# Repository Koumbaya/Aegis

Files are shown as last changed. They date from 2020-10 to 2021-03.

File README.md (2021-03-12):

# Aegis
  
 The Aegis is a keyboard that uses the same layout as the crkbd by foostan : https://github.com/foostan/crkbd
 
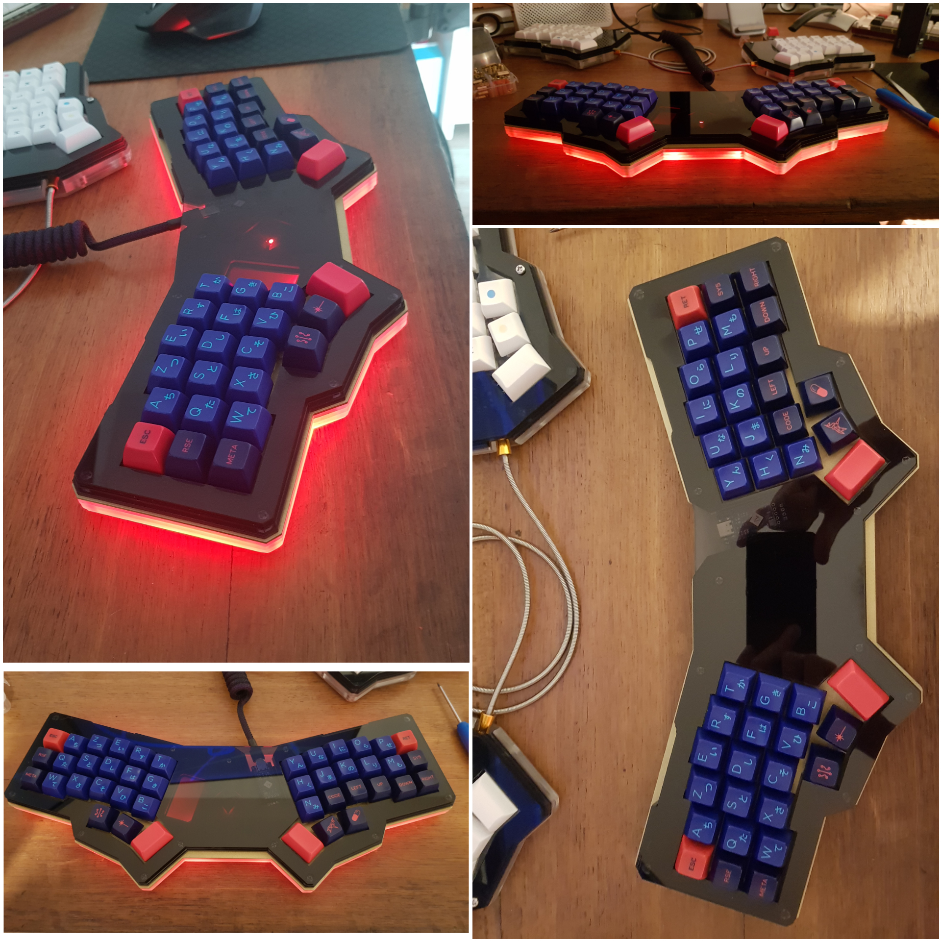
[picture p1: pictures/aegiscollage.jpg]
 
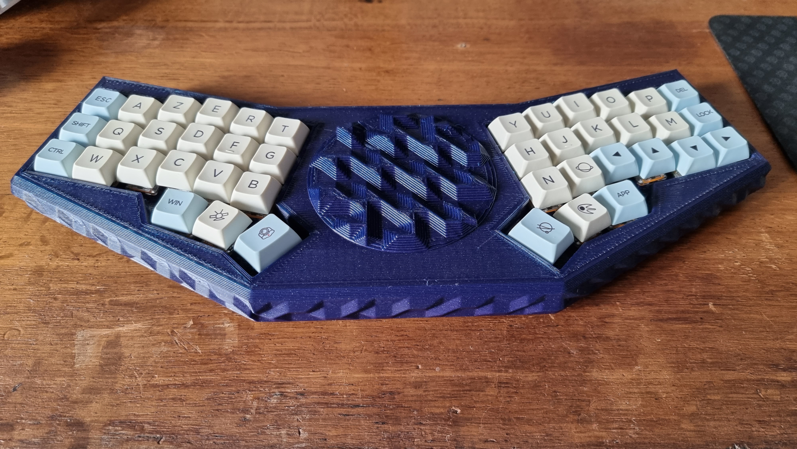
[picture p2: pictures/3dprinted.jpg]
 
 
 I wanted certain features like the solenoid so I made a quick PCB that's similar in layout to a crkbd but with only one pro-micro, you can make this PCB if you want a single PCB with underglow and a solenoid, or you can take the crkbd version of the case and slap both halves into this bad boy !
With the brass plate, it weight around 1Kg.
 
### CASE

If you're going for a metal 1,5mm switchplate (which you should, better sound yay !), you'll need to cut :
- One of every : Aegis_top1, Aegis_top2, Aegis_top3, Aegis_bottom in 3mm acrylic.
- Three times the Aegis_middle in 3mm acrylic
- One Aegis_switch_plate in 1,5mm metal of your choosing.

If you want to make everything in acrylic : just do as above minus one Aegis_middle.

You'll need 13 x M3 hex standoffs, >9mm if you have 3 "middle" part, >6 if you have only 2.
I've noticed that nylon standoffs are way larger than brass standoffs, so the dxf are designed for nylon standoff (brass ones will turn free) but can be modified.
You'll also need 13 x M3x5mm and 13 x M3x8mm screws.
The screws heads are hidden underneath the topmost plate, so you'll need something to hold it in place, probably some slim double-sided tape (will update once I've tested).
Note : be careful with the top1 and top2 cutouts, I broke mine when peeling the protective plastic sheet. (shoudn't have this problem on the crkbd version I think

### 3D printed case

This one is pretty much straightforward : print, put PCB inside, close.
There is a CRKBD version too.

 ### PCB
 
 The footprints for the diodes are either THT or SMD.
 
 The PCB uses SK6812mini-E for easier soldering, but the footprints are inverted compared to most keyboards :
 here the underglow LEDs are soldered from under the PCB (facing you when you solder them), instead of being soldered from the top. 
 
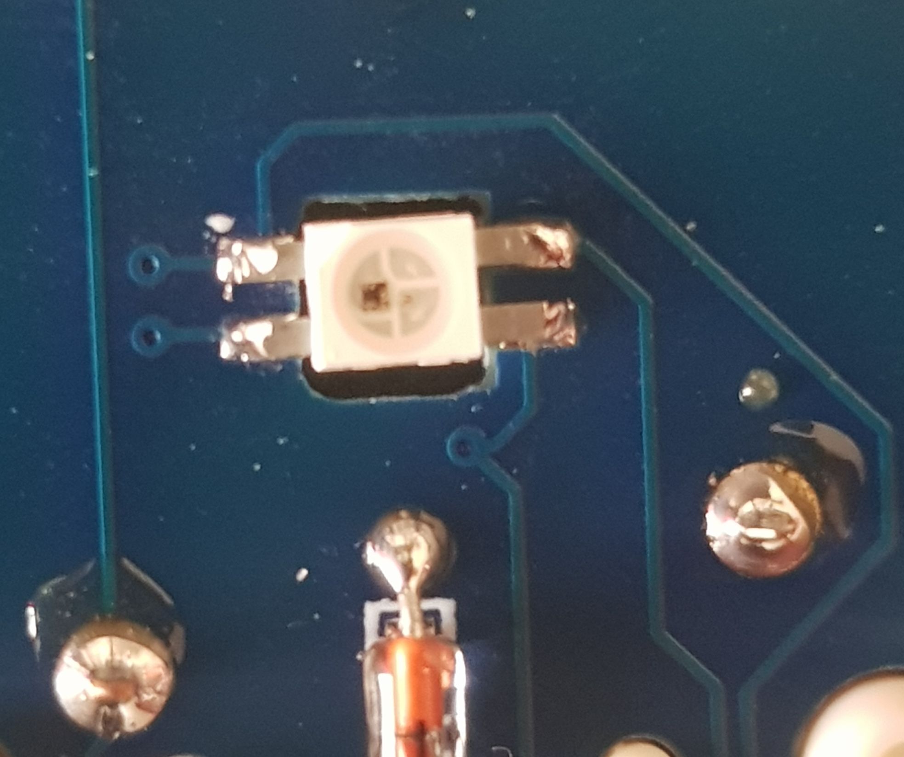
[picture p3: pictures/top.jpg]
top


(soldered from under the PCB, led facing you. beware of the different orientations : the cut tab goes with the dot on the PCB)
 
 I did this because on my previous board some of the LEDs failed after that I had soldered all of the switches, meaning that to change them I had to desolder the switches.
 
 The center LED is soldered like a switch backlight led (from under the PCB, shining towards the top, through the PCB) because it's here to shine on the plate which have a logo cutout (a version without the logo is also available, in which case you'll probably want to just jump the trace for the led from IN to OUT).
 
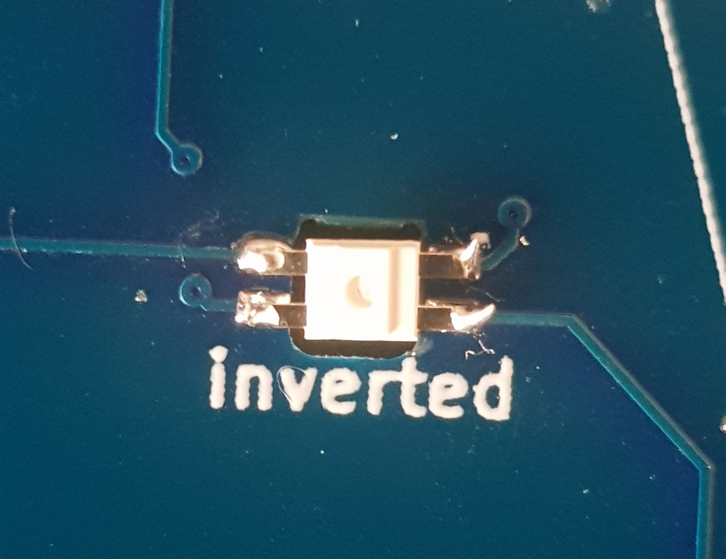
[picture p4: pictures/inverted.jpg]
inverted


(the cut tab goes on the top/right orientation, led facing back at you)

 For the solenoid you'll need 1 TIP120, 1 1N4001 diode, 1 1.1KOhms resistor and 1 5V solenoid.
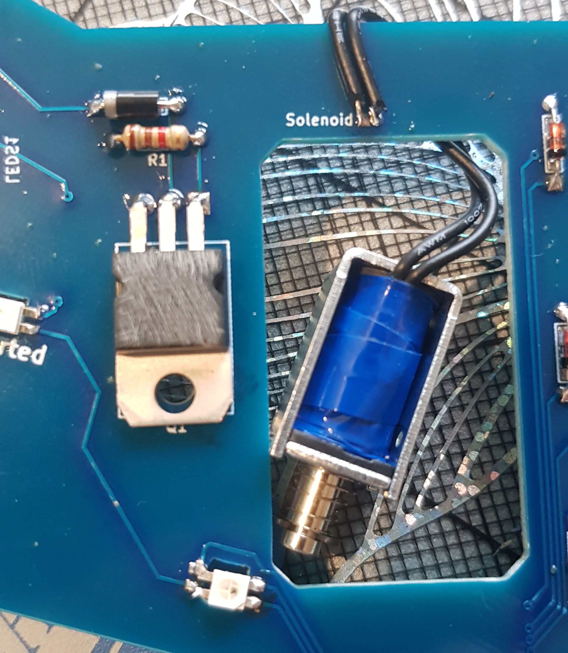
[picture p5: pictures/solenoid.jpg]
solenoid
Should look like this 
Note : in the v1.1, I've added a hole for the TIP120 because it's too big (by 0.3mm) to fit in the case. In mine I had to sand it down.

Note 2 : I couldn't get the solenoid to work :( with a pro micro I got a reboot, with the elite-c I discovered that the RAW port doesn't exist on it, so I took the VCC, with the same result. I've checked the schematics with some people and it should be good, so I'm putting in on the PCB anyway if someone want to have a crack at it(I've added 2 jumpers to get either VCC or RAW to the solenoid, if you have a pro micro, solder RAW, elite-c : solder VCC. Never both). If you find a solution let me know.

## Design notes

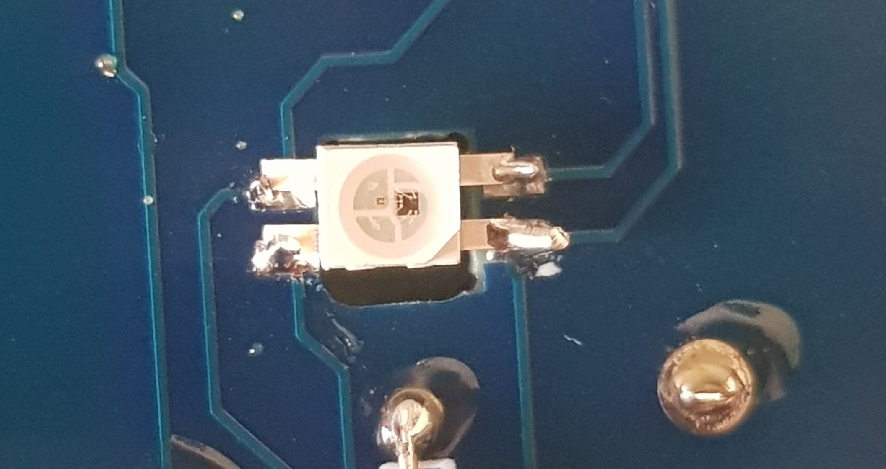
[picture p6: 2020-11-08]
pictures/bottom.jpg

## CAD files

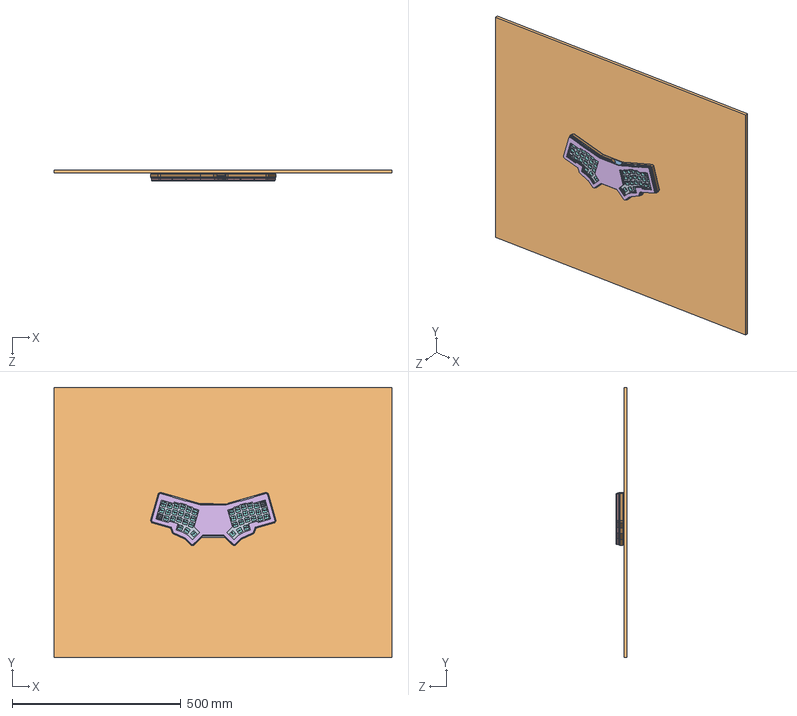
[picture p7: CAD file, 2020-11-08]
case_aegis_version/Aegis_Assemblage1.SLDASM
1000.0 x 800.0 x 33.5 mm
Aegis_switch_plate
Aegis_middle x 3
Aegis_bottom
Aegis_top1
Aegis_top2
Aegis_top3
Pièce1
pcb_export
cherry mx x 2

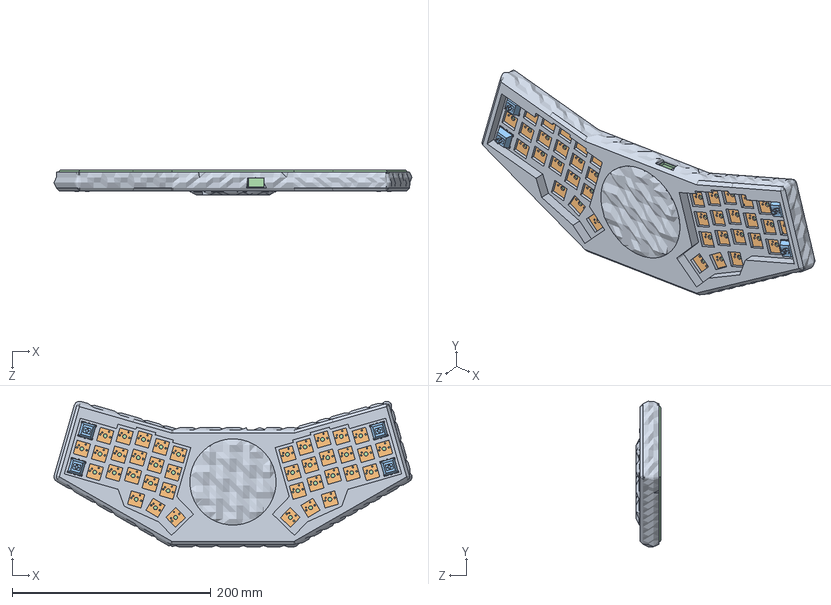
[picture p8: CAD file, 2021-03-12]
case_3D/Assemblage1.SLDASM
360.1 x 146.4 x 24.9 mm
Aegis_switch_plate_nologo
pcb_export
cherry mx x 4
bottom

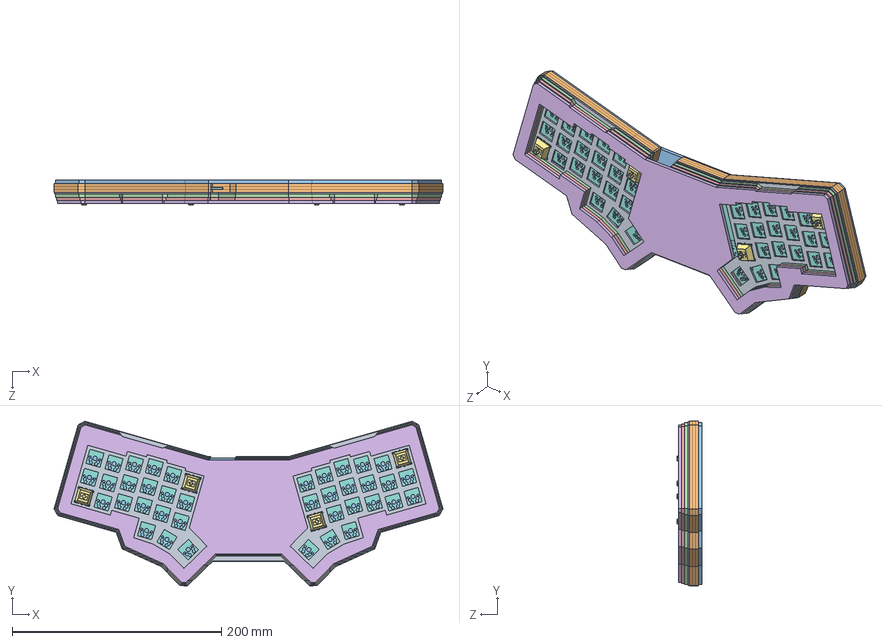
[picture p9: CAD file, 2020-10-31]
case_crkbd_version/Aegis_Assemblage1.SLDASM
371.9 x 157.4 x 23.7 mm
Aegis_switch_plate
Aegis_middle x 3
Aegis_bottom
Aegis_top1
Aegis_top2
Aegis_top3
cherry mx x 4
PCB x 2

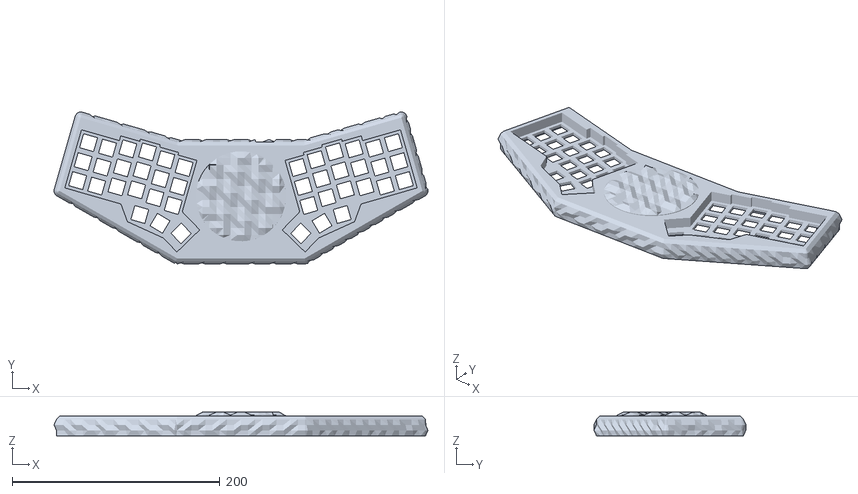
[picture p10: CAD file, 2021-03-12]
case_3D/Aegis_switch_plate_nologo.STL
360.1 x 146.4 x 22.9

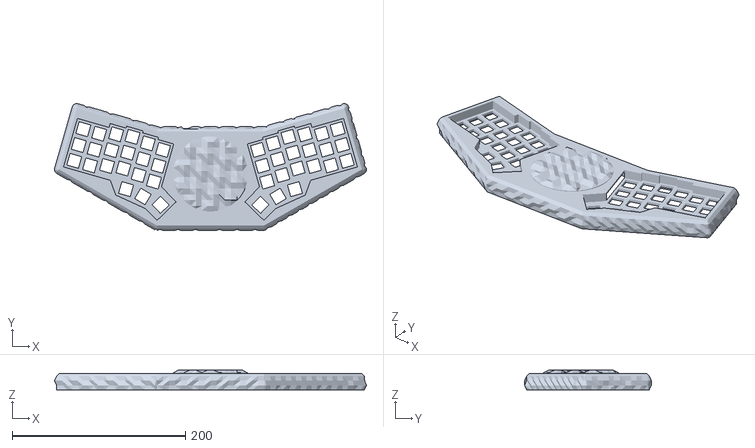
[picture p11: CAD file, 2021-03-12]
case_3D/crkbd version/Aegis_switch_plate_nologo.STL
360.1 x 146.4 x 22.9

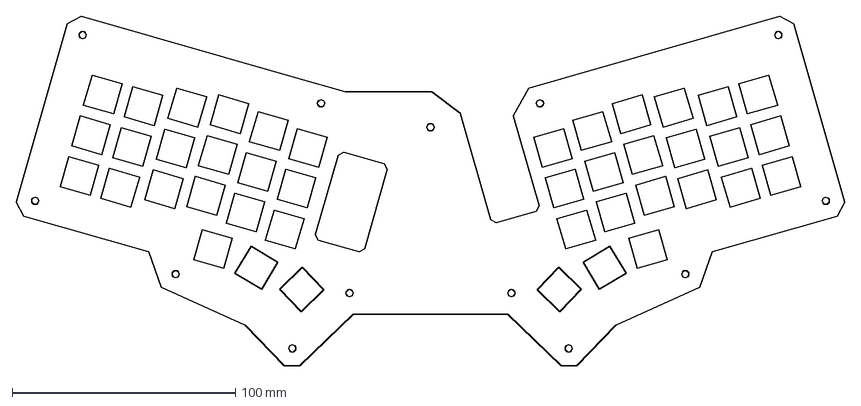
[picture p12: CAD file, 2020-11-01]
case_aegis_version/cutouts/Aegis_switch_plate_nologo.DXF
371.2 x 156.7 mm

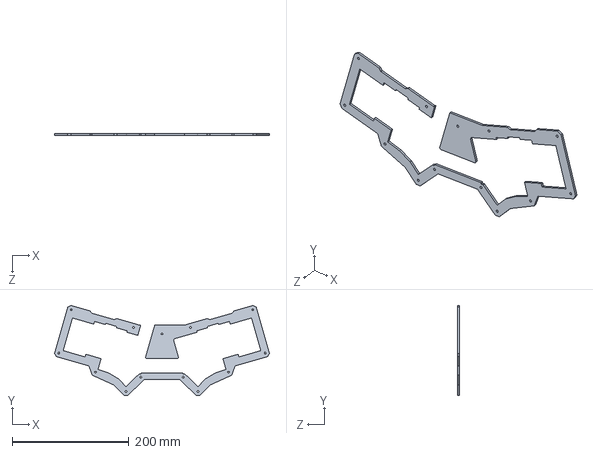
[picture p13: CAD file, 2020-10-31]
case_crkbd_version/Aegis_top1.SLDPRT
369.1 x 154.7 x 3.00 mm

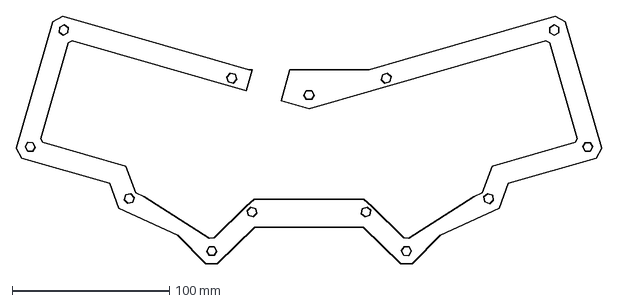
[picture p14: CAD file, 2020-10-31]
case_crkbd_version/cutouts/Aegis_middle.DXF
371.9 x 157.4 mm

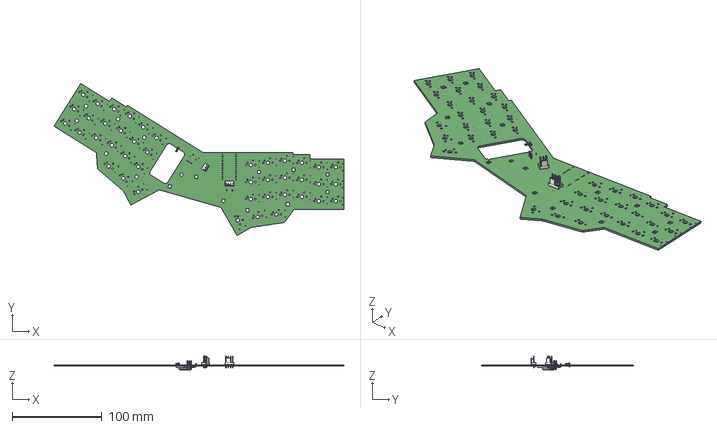
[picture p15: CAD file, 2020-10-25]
PCB/aegis/aegis.step
323.8 x 169.8 x 16.1 mm

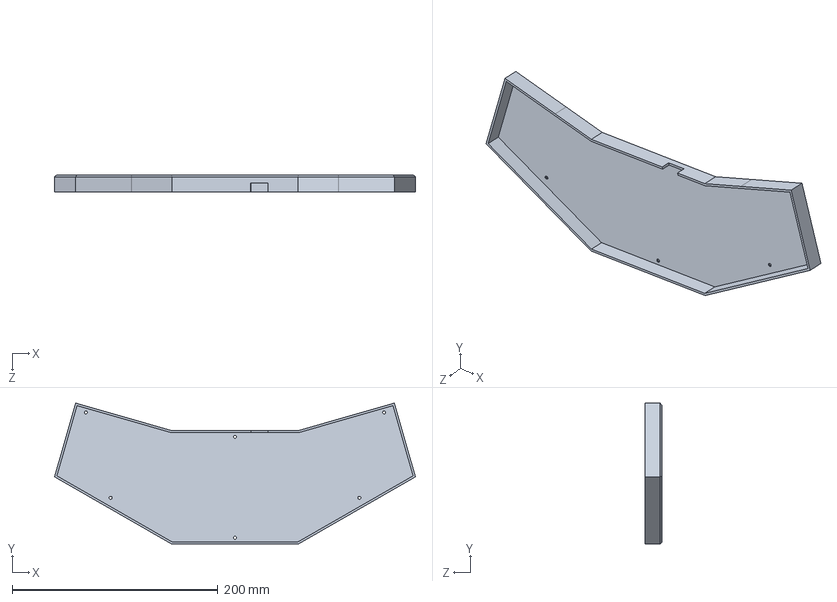
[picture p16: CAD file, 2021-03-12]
case_3D/bottom.SLDPRT
350.8 x 136.9 x 17.0 mm

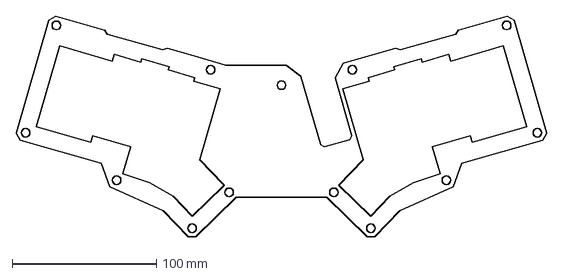
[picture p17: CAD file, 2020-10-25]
case_aegis_version/cutouts/Aegis_top2.DXF
366.9 x 152.6 mm

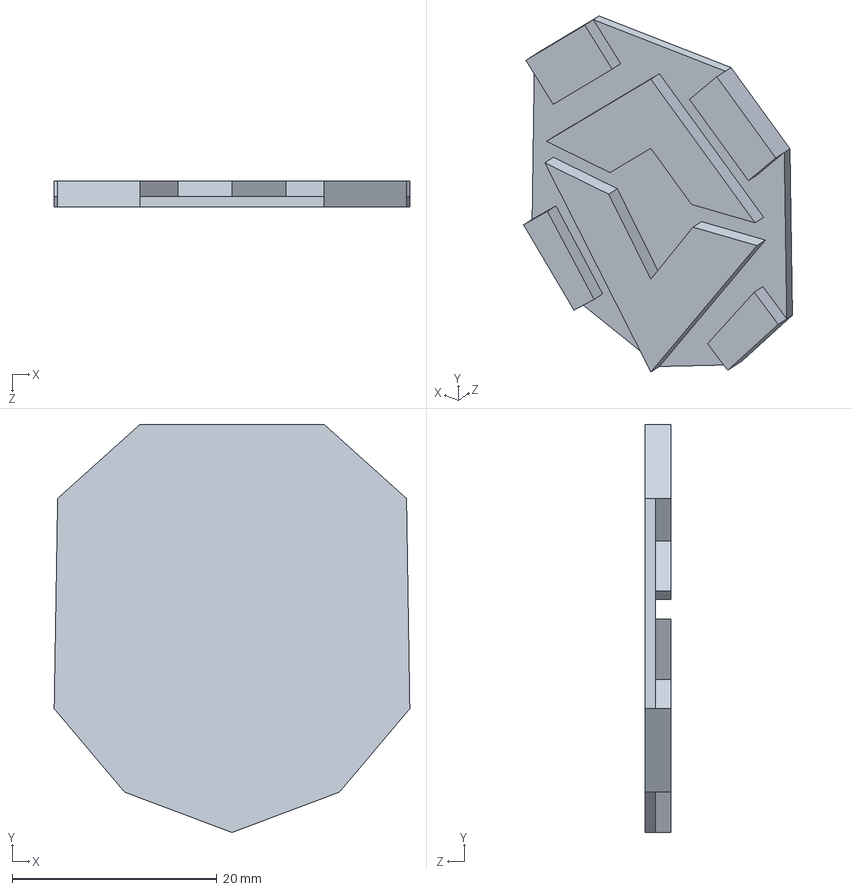
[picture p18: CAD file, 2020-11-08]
case_aegis_version/logo.SLDPRT
34.7 x 39.9 x 2.50 mm

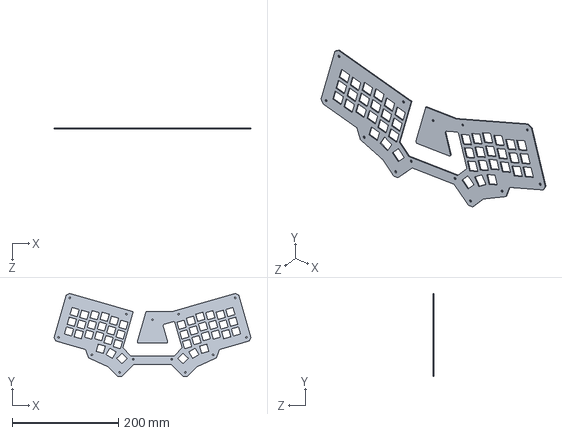
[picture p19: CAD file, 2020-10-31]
case_crkbd_version/Aegis_switch_plate.SLDPRT
371.2 x 156.7 x 1.50 mm

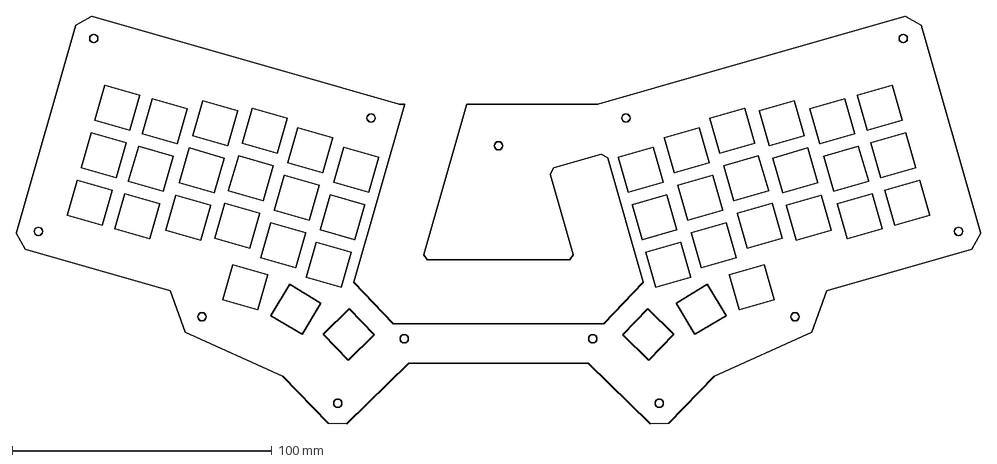
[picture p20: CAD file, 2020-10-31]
case_crkbd_version/cutouts/Aegis_switch_plate.DXF
371.2 x 156.7 mm

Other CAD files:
case_3D/crkbd version/bottom.SLDPRT
case_aegis_version/Aegis_bottom.SLDPRT
case_aegis_version/cutouts/Aegis_bottom.DXF
case_3D/bottom.STL
case_3D/crkbd version/bottom.STL
case_aegis_version/Aegis_middle.SLDPRT
case_aegis_version/Aegis_switch_plate.SLDPRT
case_aegis_version/Aegis_switch_plate_nologo.SLDPRT
case_aegis_version/Aegis_top1.SLDPRT
case_aegis_version/Aegis_top2.SLDPRT
case_aegis_version/Aegis_top3.SLDPRT
case_aegis_version/Pièce1.SLDPRT
case_aegis_version/cutouts/Aegis_middle.DXF
case_aegis_version/cutouts/Aegis_switch_plate.DXF
case_aegis_version/cutouts/Aegis_top1.DXF
case_aegis_version/cutouts/pcb_model.DXF
case_aegis_version/logo.STL
case_aegis_version/pcb_export.SLDPRT
case_aegis_version/pcb_model.SLDPRT
case_crkbd_version/Aegis_bottom.SLDPRT
case_crkbd_version/Aegis_middle.SLDPRT
case_crkbd_version/Aegis_top2.SLDPRT
case_crkbd_version/Aegis_top3.SLDPRT
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

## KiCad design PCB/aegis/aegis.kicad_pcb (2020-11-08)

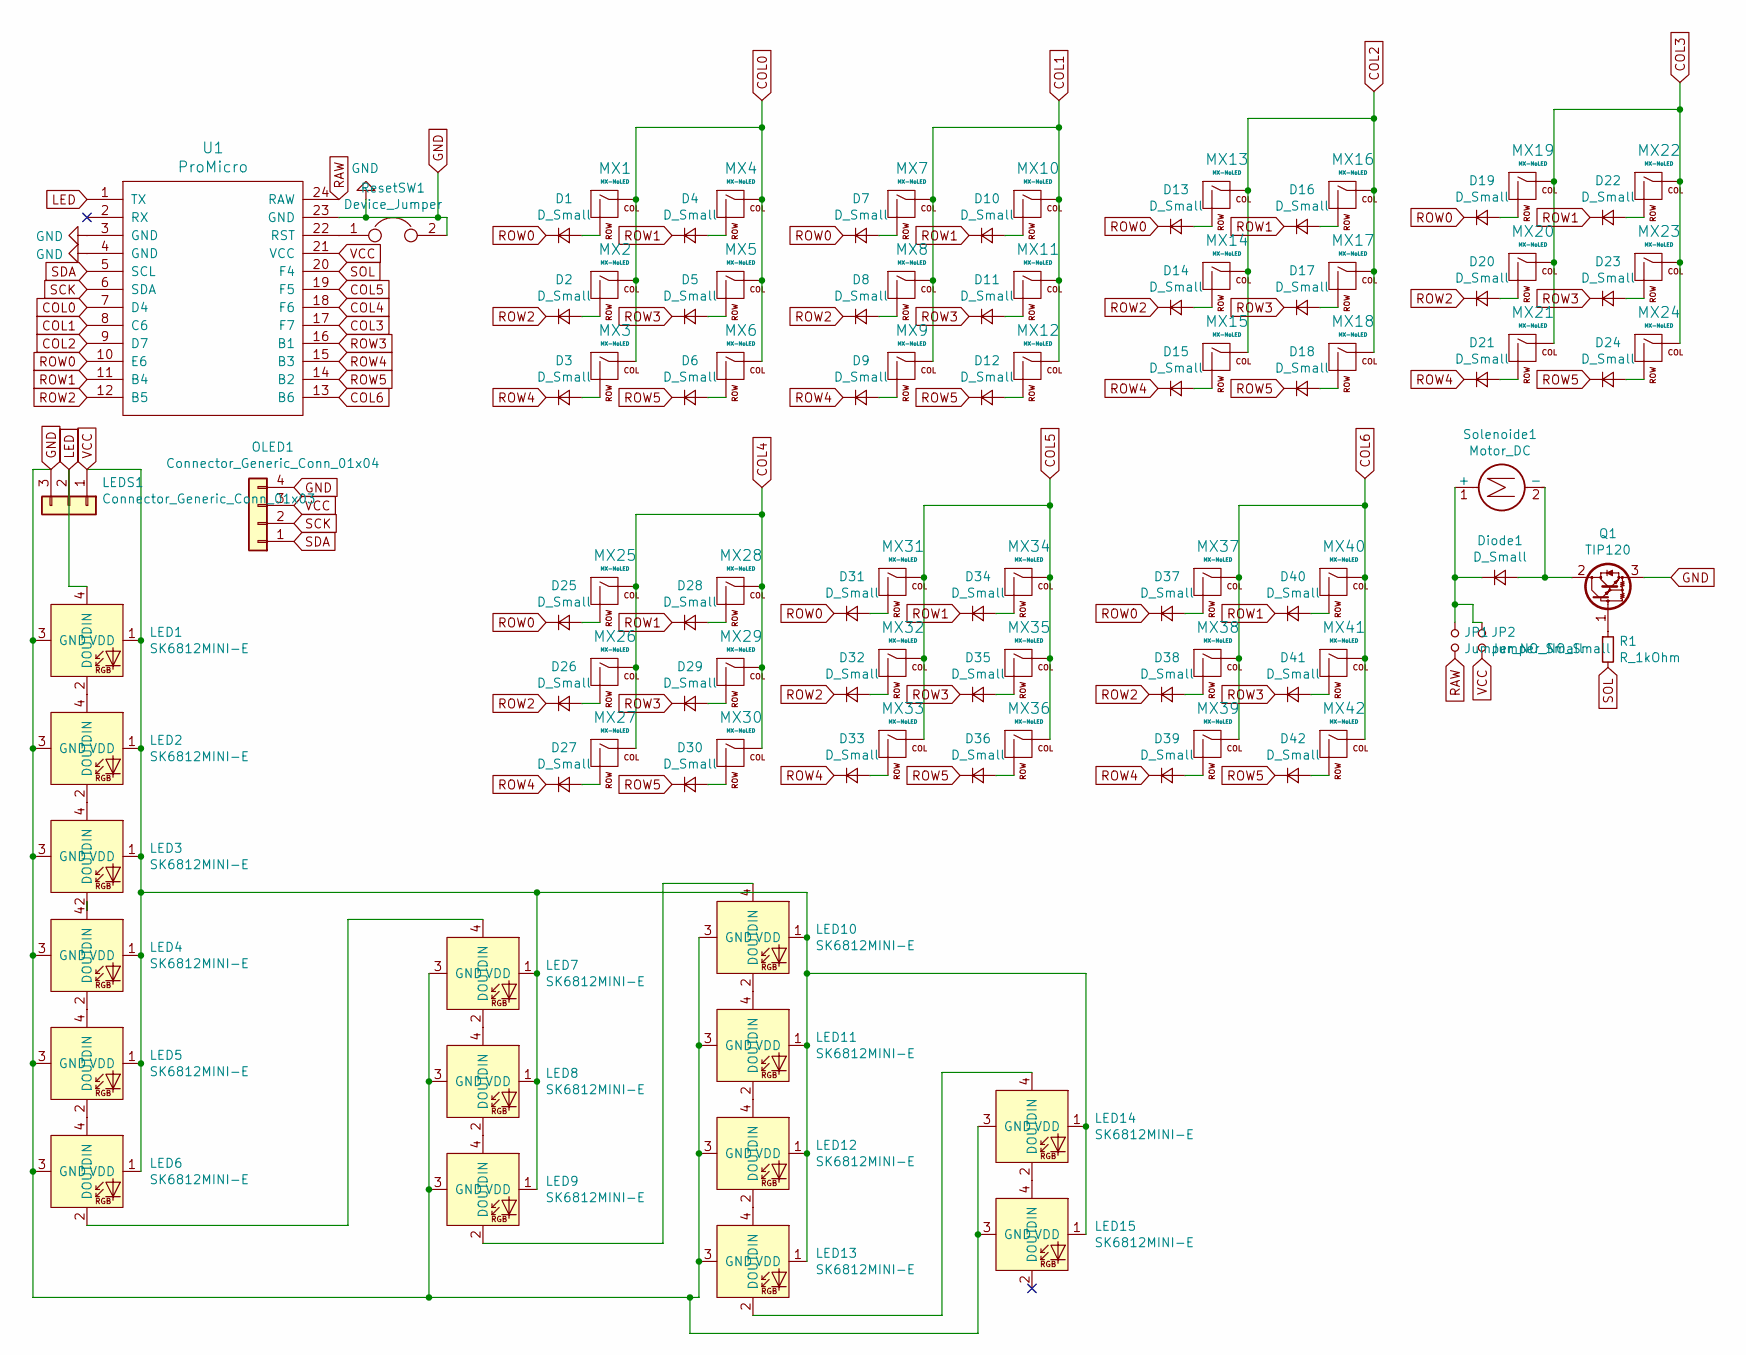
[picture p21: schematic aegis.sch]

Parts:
D1, D2, D3, D4, D5, D6, D7, D8, D9, D10, D11, D12, D13, D14, D15, D16, D17, D18, D19, D20, D21, D22, D23, D24, D25, D26, D27, D28, D29, D30, D31, D32, D33, D34, D35, D36, D37, D38, D39, D40, D41, D42: D_Small; D3_TH_SMD
Diode1: D_Small; D3_TH_SMD
JP1, JP2: Jumper_NO_Small; SolderJumper-2_P1.3mm_Open_Pad1.0x1.5mm
LED1, LED2, LED3, LED4, LED5, LED6, LED7, LED9, LED10, LED11, LED12, LED13, LED14, LED15: SK6812MINI-E; INV-YS-SK6812MINI-
LED8: SK6812MINI-E; YS-SK6812MINI-E
LEDS1: Connector_Generic_Conn_01x03; FanPinHeader_1x03_P2.54mm_Vertical
MX1, MX2, MX3, MX4, MX5, MX6, MX7, MX8, MX9, MX10, MX11, MX12, MX13, MX14, MX15, MX16, MX17, MX18, MX19, MX20, MX21, MX22, MX23, MX24, MX25, MX26, MX27, MX28, MX29, MX30, MX31, MX32, MX33, MX34, MX35, MX36, MX37, MX38, MX39, MX40, MX41, MX42: MX-NoLED; MXOnly-1U-NoLED
OLED1: Connector_Generic_Conn_01x04; FanPinHeader_1x04_P2.54mm_Vertical
Q1: TIP120; TO-220-3_Horizontal_TabDown
R1: R_1kOhm; R_Axial_DIN0204_L3.6mm_D1.6mm_P7.62mm_Horizontal
ResetSW1: Device_Jumper; ResetSW
Solenoide1: Motor_DC; ResetSW
U1: ProMicro

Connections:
COL0: MX1.1 (COL), MX2.1 (COL), MX3.1 (COL), MX4.1 (COL), MX5.1 (COL), MX6.1 (COL), U1.7 (D4)
COL1: MX7.1 (COL), MX8.1 (COL), MX9.1 (COL), MX10.1 (COL), MX11.1 (COL), MX12.1 (COL), U1.8 (C6)
COL2: MX13.1 (COL), MX14.1 (COL), MX15.1 (COL), MX16.1 (COL), MX17.1 (COL), MX18.1 (COL), U1.9 (D7)
COL3: MX19.1 (COL), MX20.1 (COL), MX21.1 (COL), MX22.1 (COL), MX23.1 (COL), MX24.1 (COL), U1.17 (F7)
COL4: MX25.1 (COL), MX26.1 (COL), MX27.1 (COL), MX28.1 (COL), MX29.1 (COL), MX30.1 (COL), U1.18 (F6)
COL5: MX31.1 (COL), MX32.1 (COL), MX33.1 (COL), MX34.1 (COL), MX35.1 (COL), MX36.1 (COL), U1.19 (F5)
COL6: MX37.1 (COL), MX38.1 (COL), MX39.1 (COL), MX40.1 (COL), MX41.1 (COL), MX42.1 (COL), U1.13 (B6)
GND: LED1.3 (GND), LED2.3 (GND), LED3.3 (GND), LED4.3 (GND), LED5.3 (GND), LED6.3 (GND), LED7.3 (GND), LED8.3 (GND), LED9.3 (GND), LED10.3 (GND), LED11.3 (GND), LED12.3 (GND), LED13.3 (GND), LED14.3 (GND), LED15.3 (GND), LEDS1.3, OLED1.4, Q1.3 (E), ResetSW1.2, U1.3 (GND), U1.4 (GND), U1.23 (GND); also elsewhere on the board
LED: LED1.4 (DIN), LEDS1.2, U1.1 (TX)
unnamed: D1.2 (A), MX1.2 (ROW)
unnamed: D2.2 (A), MX2.2 (ROW)
unnamed: D3.2 (A), MX3.2 (ROW)
unnamed: D4.2 (A), MX4.2 (ROW)
unnamed: D5.2 (A), MX5.2 (ROW)
unnamed: D6.2 (A), MX6.2 (ROW)
unnamed: D7.2 (A), MX7.2 (ROW)
unnamed: D8.2 (A), MX8.2 (ROW)
unnamed: D9.2 (A), MX9.2 (ROW)
unnamed: D10.2 (A), MX10.2 (ROW)
unnamed: D11.2 (A), MX11.2 (ROW)
unnamed: D12.2 (A), MX12.2 (ROW)
unnamed: D13.2 (A), MX13.2 (ROW)
unnamed: D14.2 (A), MX14.2 (ROW)
unnamed: D15.2 (A), MX15.2 (ROW)
unnamed: D16.2 (A), MX16.2 (ROW)
unnamed: D17.2 (A), MX17.2 (ROW)
unnamed: D18.2 (A), MX18.2 (ROW)
unnamed: D19.2 (A), MX19.2 (ROW)
unnamed: D20.2 (A), MX20.2 (ROW)
unnamed: D21.2 (A), MX21.2 (ROW)
unnamed: D22.2 (A), MX22.2 (ROW)
unnamed: D23.2 (A), MX23.2 (ROW)
unnamed: D24.2 (A), MX24.2 (ROW)
unnamed: D25.2 (A), MX25.2 (ROW)
unnamed: D26.2 (A), MX26.2 (ROW)
unnamed: D27.2 (A), MX27.2 (ROW)
unnamed: D28.2 (A), MX28.2 (ROW)
unnamed: D29.2 (A), MX29.2 (ROW)
unnamed: D30.2 (A), MX30.2 (ROW)
unnamed: D31.2 (A), MX31.2 (ROW)
unnamed: D32.2 (A), MX32.2 (ROW)
unnamed: D33.2 (A), MX33.2 (ROW)
unnamed: D34.2 (A), MX34.2 (ROW)
unnamed: D35.2 (A), MX35.2 (ROW)
unnamed: D36.2 (A), MX36.2 (ROW)
unnamed: D37.2 (A), MX37.2 (ROW)
unnamed: D38.2 (A), MX38.2 (ROW)
unnamed: D39.2 (A), MX39.2 (ROW)
unnamed: D40.2 (A), MX40.2 (ROW)
unnamed: D41.2 (A), MX41.2 (ROW)
unnamed: D42.2 (A), MX42.2 (ROW)
unnamed 51: Diode1.1 (K), JP1.1, JP2.1, Solenoide1.1 (+); also elsewhere on the board
unnamed: Diode1.2 (A), Q1.2 (C), Solenoide1.2 (-)
unnamed: LED1.2 (DOUT), LED2.4 (DIN)
unnamed: LED2.2 (DOUT), LED3.4 (DIN)
unnamed: LED3.2 (DOUT), LED4.4 (DIN)
unnamed: LED4.2 (DOUT), LED5.4 (DIN)
unnamed: LED5.2 (DOUT), LED6.4 (DIN)
unnamed: LED6.2 (DOUT), LED7.4 (DIN)
unnamed: LED7.2 (DOUT), LED8.4 (DIN)
unnamed: LED8.2 (DOUT), LED9.4 (DIN)
unnamed: LED10.2 (DOUT), LED11.4 (DIN)
unnamed: LED9.2 (DOUT), LED10.4 (DIN)
unnamed: LED11.2 (DOUT), LED12.4 (DIN)
unnamed: LED12.2 (DOUT), LED13.4 (DIN)
unnamed: LED13.2 (DOUT), LED14.4 (DIN)
unnamed: LED14.2 (DOUT), LED15.4 (DIN)
unnamed: Q1.1 (B), R1.1
unnamed: ResetSW1.1, U1.22 (RST)
RAW: JP1.2, U1.24 (RAW); also elsewhere on the board
ROW0: D1.1 (K), D7.1 (K), D13.1 (K), D19.1 (K), D25.1 (K), D31.1 (K), D37.1 (K), U1.10 (E6)
ROW1: D4.1 (K), D10.1 (K), D16.1 (K), D22.1 (K), D28.1 (K), D34.1 (K), D40.1 (K), U1.11 (B4)
ROW2: D2.1 (K), D8.1 (K), D14.1 (K), D20.1 (K), D26.1 (K), D32.1 (K), D38.1 (K), U1.12 (B5)
ROW3: D5.1 (K), D11.1 (K), D17.1 (K), D23.1 (K), D29.1 (K), D35.1 (K), D41.1 (K), U1.16 (B1)
ROW4: D3.1 (K), D9.1 (K), D15.1 (K), D21.1 (K), D27.1 (K), D33.1 (K), D39.1 (K), U1.15 (B3)
ROW5: D6.1 (K), D12.1 (K), D18.1 (K), D24.1 (K), D30.1 (K), D36.1 (K), D42.1 (K), U1.14 (B2)
SCK: OLED1.2, U1.6 (SDA); also elsewhere on the board
SDA: OLED1.1, U1.5 (SCL); also elsewhere on the board
SOL: R1.2, U1.20 (F4)
VCC: JP2.2, LED1.1 (VDD), LED2.1 (VDD), LED3.1 (VDD), LED4.1 (VDD), LED5.1 (VDD), LED6.1 (VDD), LED7.1 (VDD), LED8.1 (VDD), LED9.1 (VDD), LED10.1 (VDD), LED11.1 (VDD), LED12.1 (VDD), LED13.1 (VDD), LED14.1 (VDD), LED15.1 (VDD), LEDS1.1, OLED1.3, U1.21 (VCC); also elsewhere on the board

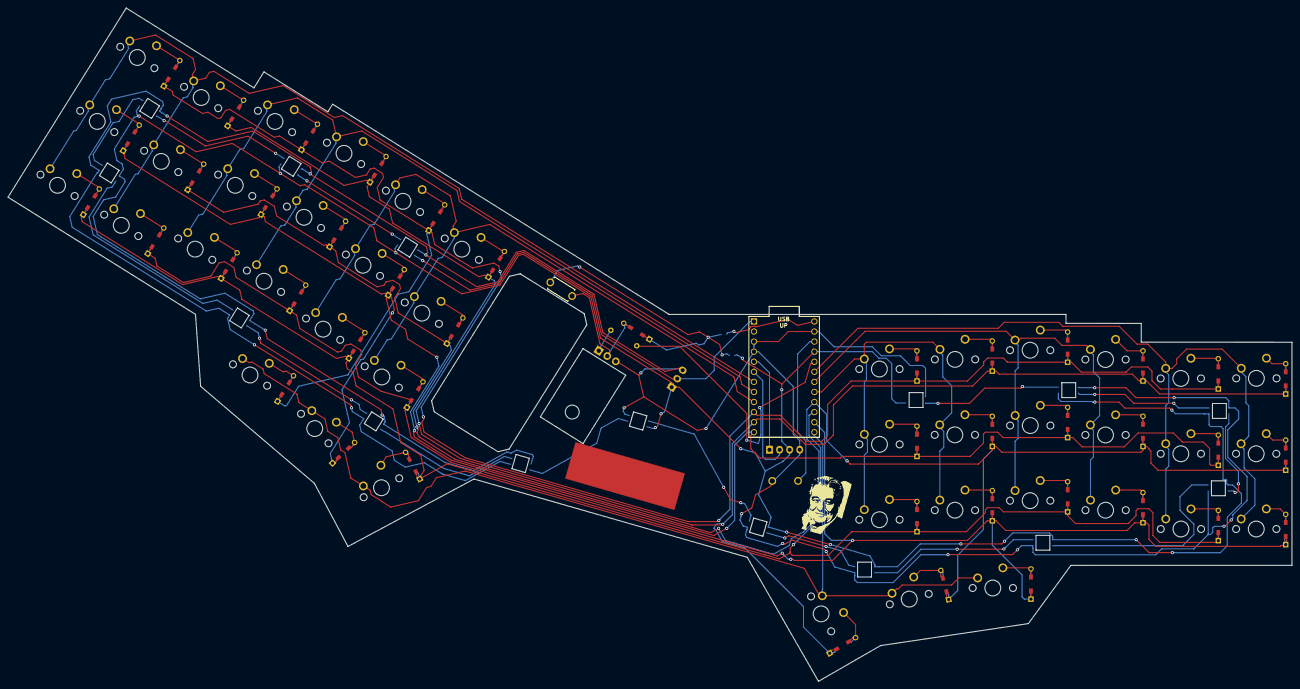
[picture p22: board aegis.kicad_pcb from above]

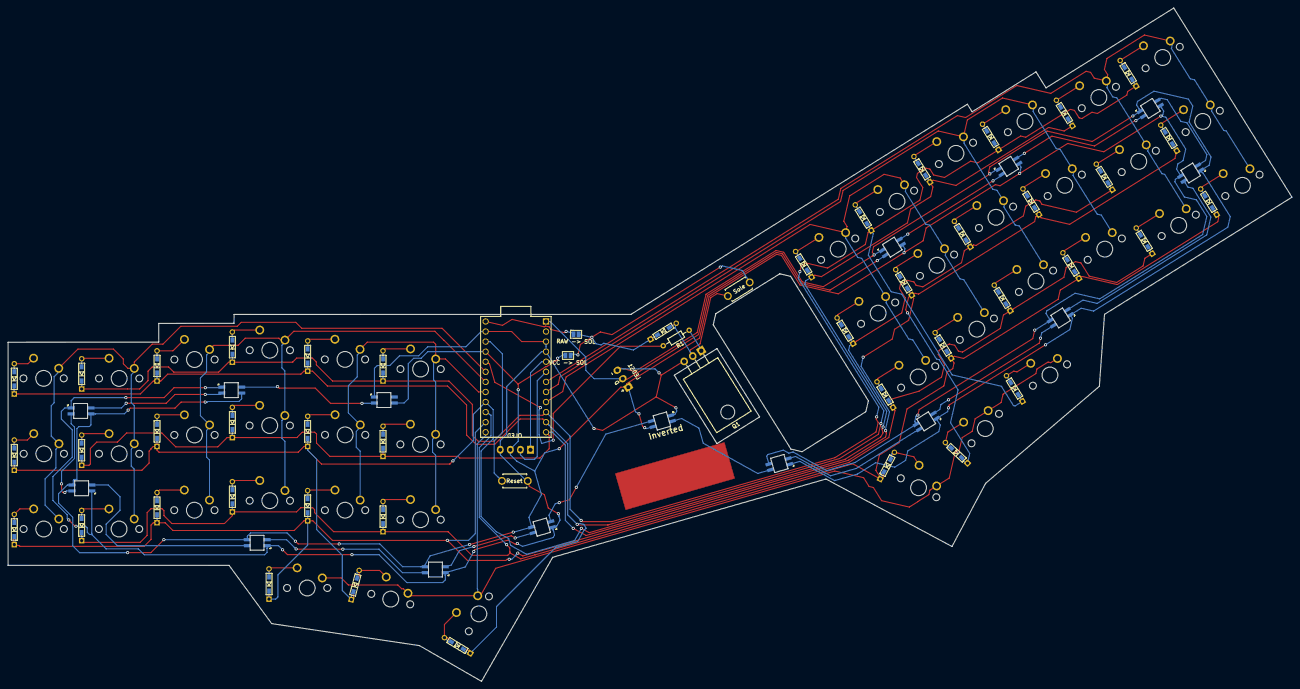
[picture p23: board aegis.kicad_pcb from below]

Board: 2 copper layers, 323.8 x 169.8 mm, 109 parts (5 on the bottom side), 80 nets.

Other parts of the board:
OLED: Connector_Generic_Conn_01x04; FanPinHeader_1x04_P2.54mm_Vertical
RAW -> SOL: Jumper_NO_Small; SolderJumper-2_P1.3mm_Open_Pad1.0x1.5mm
VCC -> SOL: Jumper_NO_Small; SolderJumper-2_P1.3mm_Open_Pad1.0x1.5mm

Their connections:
GND: OLED.4; also elsewhere on the board
unnamed 51: RAW -> SOL.1, VCC -> SOL.1; also elsewhere on the board
RAW: RAW -> SOL.2; also elsewhere on the board
SCK: OLED.2; also elsewhere on the board
SDA: OLED.1; also elsewhere on the board
VCC: OLED.3, VCC -> SOL.2; also elsewhere on the board

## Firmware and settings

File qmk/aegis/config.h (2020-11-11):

#ifndef CONFIG_H
#define CONFIG_H

#include "config_common.h"

/* USB Device descriptor parameter */
#define VENDOR_ID       0xFEED
#define PRODUCT_ID      0x6060
#define DEVICE_VER      0x0001
#define MANUFACTURER    qmkbuilder
#define PRODUCT         aegis
#define DESCRIPTION     Keyboard

/* key matrix size */
#define MATRIX_ROWS 6
#define MATRIX_COLS 7

/* key matrix pins */
#define MATRIX_ROW_PINS { E6, B4, B5, B1, B3, B2 }
#define MATRIX_COL_PINS { D4, C6, D7, F7, F6, F5, B6}
#define UNUSED_PINS

/* COL2ROW or ROW2COL */
#define DIODE_DIRECTION COL2ROW

#define USE_I2C

/* number of backlight levels */
#define SSD1306OLED

//define BACKLIGHT_PIN D3
#ifdef BACKLIGHT_PIN
#define BACKLIGHT_LEVELS 16
#endif

/* Set 0 if debouncing isn't needed */
#define DEBOUNCING_DELAY 5

//define DRIVER_LED_TOTAL 8

/* Mechanical locking support. Use KC_LCAP, KC_LNUM or KC_LSCR instead in keymap */
#define LOCKING_SUPPORT_ENABLE

/* Locking resynchronize hack */
#define LOCKING_RESYNC_ENABLE

/* key combination for command */
#define IS_COMMAND() ( \
    keyboard_report->mods == (MOD_BIT(KC_LSHIFT) | MOD_BIT(KC_RSHIFT)) \
)

/* prevent stuck modifiers */
#define PREVENT_STUCK_MODIFIERS

#define RGB_DI_PIN D3
#ifdef RGB_DI_PIN
#define RGBLIGHT_ANIMATIONS
#define RGBLIGHT_EFFECT_KNIGHT
#define RGBLIGHT_EFFECT_RAINBOW_SWIRL
#define RGBLED_NUM 15
#define DRIVER_LED_TOTAL 15
#define RGBLIGHT_LIMIT_VAL 240
#define RGBLIGHT_HUE_STEP 10
#define RGBLIGHT_SAT_STEP 17
#define RGBLIGHT_VAL_STEP 17
#endif

#endif

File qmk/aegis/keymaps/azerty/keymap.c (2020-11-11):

#include "aegis.h"
#include "keymap_french.h"
#include <avr/io.h>
#include <timer.h>
#include "pincontrol.h"
#include <string.h>
#include "action_layer.h"
#ifdef SSD1306OLED
  #include "ssd1306.h"
#endif
#ifdef RGBLIGHT_ENABLE
//Following line allows macro to read current RGB settings
extern rgblight_config_t rgblight_config;
#endif
#define _QWERTY 0
#define _RAISE 1
#define _LOWER 2
#define _ADJUST 3

#define SOLENOID_DEFAULT_DWELL 12 
#define SOLENOID_MAX_DWELL 100
#define SOLENOID_MIN_DWELL 4
#define SOLENOID_PIN F4

bool solenoid_enabled = true;
bool solenoid_on = false;
bool solenoid_buzz = false;
bool solenoid_buzzing = false;
volatile uint32_t solenoid_start = 0;
uint8_t solenoid_dwell = SOLENOID_DEFAULT_DWELL;

enum custom_keycodes {
  QWERTY = SAFE_RANGE,
  RAISE,
  LOWER,
  ADJUST,
  BACKLIT,
  SOLENOID_TOG,
  SOLENOID_DWELL_MINUS,
  SOLENOID_DWELL_PLUS,
  SOLENOID_BUZZ_ON,
  SOLENOID_BUZZ_OFF
};
// FR_OVRR, FR_PLUS,
const uint16_t PROGMEM keymaps[][MATRIX_ROWS][MATRIX_COLS] = {

	KEYMAP(
  KC_ESC,           FR_A,   FR_Z,   KC_E,   KC_R,   KC_T,            KC_Y,  KC_U,   KC_I,   KC_O,   KC_P,   KC_BSPACE,   \
  LSFT_T(KC_TAB),   FR_Q,   KC_S,   KC_D,   KC_F,   KC_G,            KC_H,  KC_J,   KC_K,   KC_L,   FR_M,   KC_DELETE,   \
  KC_LCTRL,         FR_W,   KC_X,   KC_C,   KC_V,   KC_B,            KC_N,  KC_M,   KC_LEFT,   KC_UP,   KC_DOWN,   KC_RIGHT,   \
               KC_LGUI,   MO(_LOWER),   LALT_T(KC_SPC),             RSFT_T(KC_ENT),   MO(_RAISE),   MO(_ADJUST)\
),   
	KEYMAP(
    FR_AMP, FR_EACU, FR_QUOT, FR_APOS, FR_LPRN, FR_MINS,               FR_EGRV, FR_UNDS, FR_CCED, FR_AGRV, FR_RPRN, FR_EQL,
    LSFT_T(KC_TAB),   KC_NO,   KC_NO, KC_BSLS, KC_TILD, KC_NUHS,               KC_LCBR, KC_QUOT, KC_BSLS, KC_LBRC, KC_RBRC, KC_DEL,
    KC_LCTRL, KC_NUBS,   KC_NO,   KC_NO,   KC_NO,   KC_NO,                 KC_NO,    KC_M, KC_COMM,  KC_DOT, KC_SLSH,  KC_NO, 
                               _______, _______, _______,               _______, _______, _______
),

	KEYMAP(
         FR_1,   FR_2,    FR_3,    FR_4,    FR_5,    FR_6,                 FR_7,    FR_8,    FR_9,    FR_0, FR_OVRR, FR_PLUS, \
      LSFT_T(KC_TAB),  KC_F1,   KC_F2,   KC_F3,   KC_F4,   KC_F5,                KC_F6,   KC_F7,   KC_F8,   KC_F9,  KC_F10,  KC_DEL, \
      KC_LCTRL, KC_F11,  KC_F12, KC_COPY, KC_PSTE,   KC_NO,                KC_NO, KC_COMM, KC_HOME, KC_PGDN, KC_PGUP,  KC_END, \
                                _______, _______, _______,              _______, _______, _______ \
),

	KEYMAP(
      _______, FR_TILD, FR_HASH, ALGR(KC_E), FR_LCBR, FR_LBRC,          FR_GRV, FR_BSLS, FR_CCIRC,   FR_AT, FR_RBRC, FR_RCBR, \
      RGB_MOD, RGB_TOG, RGB_VAI,    RGB_SAI, RGB_HUI, FR_LCBR,         _______, FR_PERC,  _______, _______, _______, FR_RCBR, \
      RGB_RMOD, _______, RGB_VAD,    RGB_SAD, RGB_HUD, FR_LPRN,         FR_PIPE, FR_QUES,   FR_DOT, FR_SLSH, FR_SECT, _______, \
                                    _______, _______, _______,         _______, _______, _______
),
  KEYMAP(
    _______, RGB_MOD, RGB_HUI, RGB_SAI, RGB_VAI, RGB_TOG,                _______, _______, _______, _______, _______, RESET,
    _______,    _______ , _______, _______, _______,  RGB_MOD,     _______, _______,  _______, _______,  _______, EEP_RST,
    _______, RGB_RMOD,RGB_HUD,RGB_SAD, RGB_VAD, RGB_RMOD,                _______, _______, _______, _______, _______, _______,
                                     _______, _______, _______,        _______, _______, _______
    )

};

const uint16_t PROGMEM fn_actions[] = {

};

void solenoid_buzz_on(void) {
  solenoid_buzz = true;
}

void solenoid_buzz_off(void) {
  solenoid_buzz = false;
}

void solenoid_dwell_minus(void) {
  if (solenoid_dwell > 0) solenoid_dwell--;
}

void solenoid_dwell_plus(void) {
  if (solenoid_dwell < SOLENOID_MAX_DWELL) solenoid_dwell++;
}

void solenoid_toggle(void) {
  solenoid_enabled = !solenoid_enabled;
}

void solenoid_stop(void) {
  digitalWrite(SOLENOID_PIN, PinLevelLow); 
  solenoid_on = false;
  solenoid_buzzing = false;
}

void solenoid_fire(void) {
  if (!solenoid_enabled) return;

  if (!solenoid_buzz && solenoid_on) return;
  if (solenoid_buzz && solenoid_buzzing) return;

  solenoid_on = true;
  solenoid_buzzing = true;
  solenoid_start = timer_read32();
  digitalWrite(SOLENOID_PIN, PinLevelHigh);
}

void solenoid_check(void) {
  uint32_t elapsed = 0;

  if (!solenoid_on) return;

  elapsed = timer_elapsed32(solenoid_start);

  //Check if it's time to finish this solenoid click cycle 
  if (elapsed > solenoid_dwell) {
    solenoid_stop();
    return;
  }

  //Check whether to buzz the solenoid on and off
  if (solenoid_buzz) {
    if (elapsed / SOLENOID_MIN_DWELL % 2 == 0){
      if (!solenoid_buzzing) {
        solenoid_buzzing = true;
        digitalWrite(SOLENOID_PIN, PinLevelHigh);
      }
    }
    else {
      if (solenoid_buzzing) {
        solenoid_buzzing = false;
        digitalWrite(SOLENOID_PIN, PinLevelLow);
      }
    }
  }

}

void solenoid_setup(void) {
  pinMode(SOLENOID_PIN, PinDirectionOutput);
  digitalWrite(SOLENOID_PIN, PinLevelLow);
  timer_init();
}


int RGB_current_mode;

void persistent_default_layer_set(uint16_t default_layer) {
  eeconfig_update_default_layer(default_layer);
  default_layer_set(default_layer);
}

void matrix_init_user(void) {
  solenoid_setup();
	#ifdef RGBLIGHT_ENABLE
      RGB_current_mode = rgblight_config.mode;
    #endif
    //SSD1306 OLED init, make sure to add #define SSD1306OLED in config.h
    #ifdef SSD1306OLED
        iota_gfx_init(false);   // turns on the display
    #endif
}


// When add source files to SRC in rules.mk, you can use functions.
const char *read_layer_state(void);
const char *read_logo(void);
void set_keylog(uint16_t keycode, keyrecord_t *record);
const char *read_keylog(void);
const char *read_keylogs(void);

void matrix_scan_user(void) {
  solenoid_check();
	  iota_gfx_task();
}

void matrix_render_user(struct CharacterMatrix *matrix) {
  if (true) {
    // If you want to change the display of OLED, you need to change here
    matrix_write_ln(matrix, read_layer_state());
    matrix_write_ln(matrix, read_keylog());
    matrix_write_ln(matrix, read_keylogs());
    //matrix_write_ln(matrix, read_mode_icon(keymap_config.swap_lalt_lgui));
    //matrix_write_ln(matrix, read_host_led_state());
    //matrix_write_ln(matrix, read_timelog());
  } else {
    matrix_write(matrix, read_logo());
  }
}

void matrix_update(struct CharacterMatrix *dest, const struct CharacterMatrix *source) {
  if (memcmp(dest->display, source->display, sizeof(dest->display))) {
    memcpy(dest->display, source->display, sizeof(dest->display));
    dest->dirty = true;
  }
}

void iota_gfx_task_user(void) {
  struct CharacterMatrix matrix;
  matrix_clear(&matrix);
  matrix_render_user(&matrix);
  matrix_update(&display, &matrix);
}
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

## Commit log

2020-10-25 moved files
    [1middle_1middle.DXF, Aegis_Assemblage1.SLDASM, Aegis_bottom.DXF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]
2020-10-31 add crkbd version
    [Aegis_Assemblage1.SLDASM, Aegis_bottom.DXF, Aegis_bottom.SLDPRT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]
2020-10-31 erased a file by mistake
    [Aegis_bottom.DXF]
2020-11-01 change colors
    [Aegis_Assemblage1.SLDASM, Aegis_bottom.SLDPRT, Aegis_middle.SLDPRT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]
2020-11-08 update PCB to v1.1
    [Aegis_Assemblage1.SLDASM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]
2021-03-12 add 3d printed case
    [Aegis_switch_plate_nologo.STL, Assemblage1.SLDASM, bottom.SLDPRT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]
